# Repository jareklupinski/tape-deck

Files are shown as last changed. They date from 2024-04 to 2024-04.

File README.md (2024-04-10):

# tape-deck
a user-unfriendly design

rotating2
```
to play music, just give it a tape.
tape-deck plays to end of the tape,
reverses, and plays the other side.
```
tapedeck_1
```
HOW DOES ONE PAUSE / STOP THE TAPE?
you should finish what you started.
```
tapedeck_2
```
HOW DO I MAKE IT LOUDER OR QUIETER?
listen to louder or quieter albums.
```
tapedeck_3
```
CAN I FASTFORWARD OR REWIND AT ALL?
the artists who recorded this album
want you to listen to it like this.
```
tapedeck_4

thank you

tapedeck_5

# MAKING OF

Circuit Board Design


Schematic


Enclosure


Code
Derived from https://github.com/elehobica/pico_crp42602y_ctrl/tree/main

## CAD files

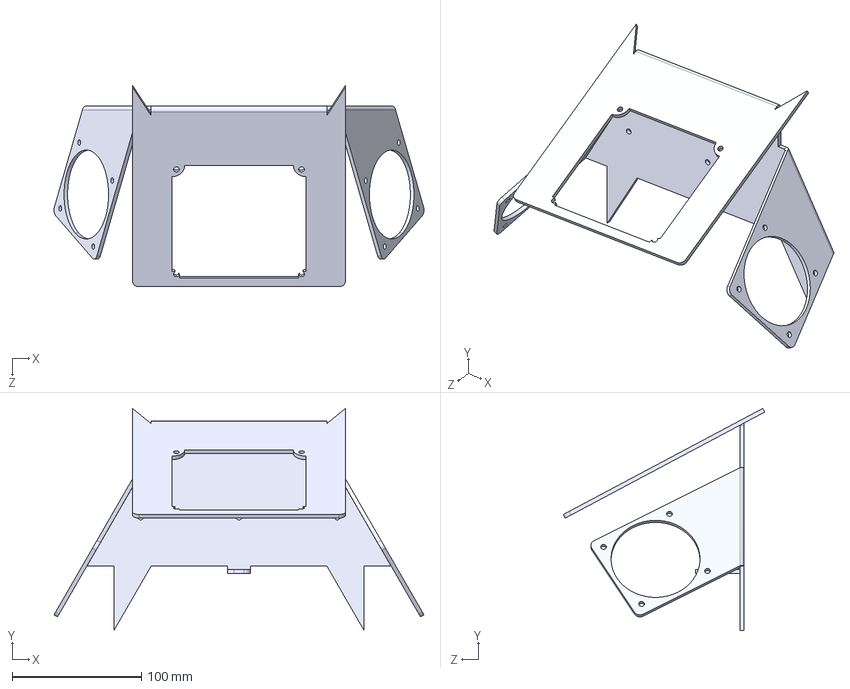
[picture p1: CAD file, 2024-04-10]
tape-deck.STEP
286.8 x 172.2 x 156.1 mm

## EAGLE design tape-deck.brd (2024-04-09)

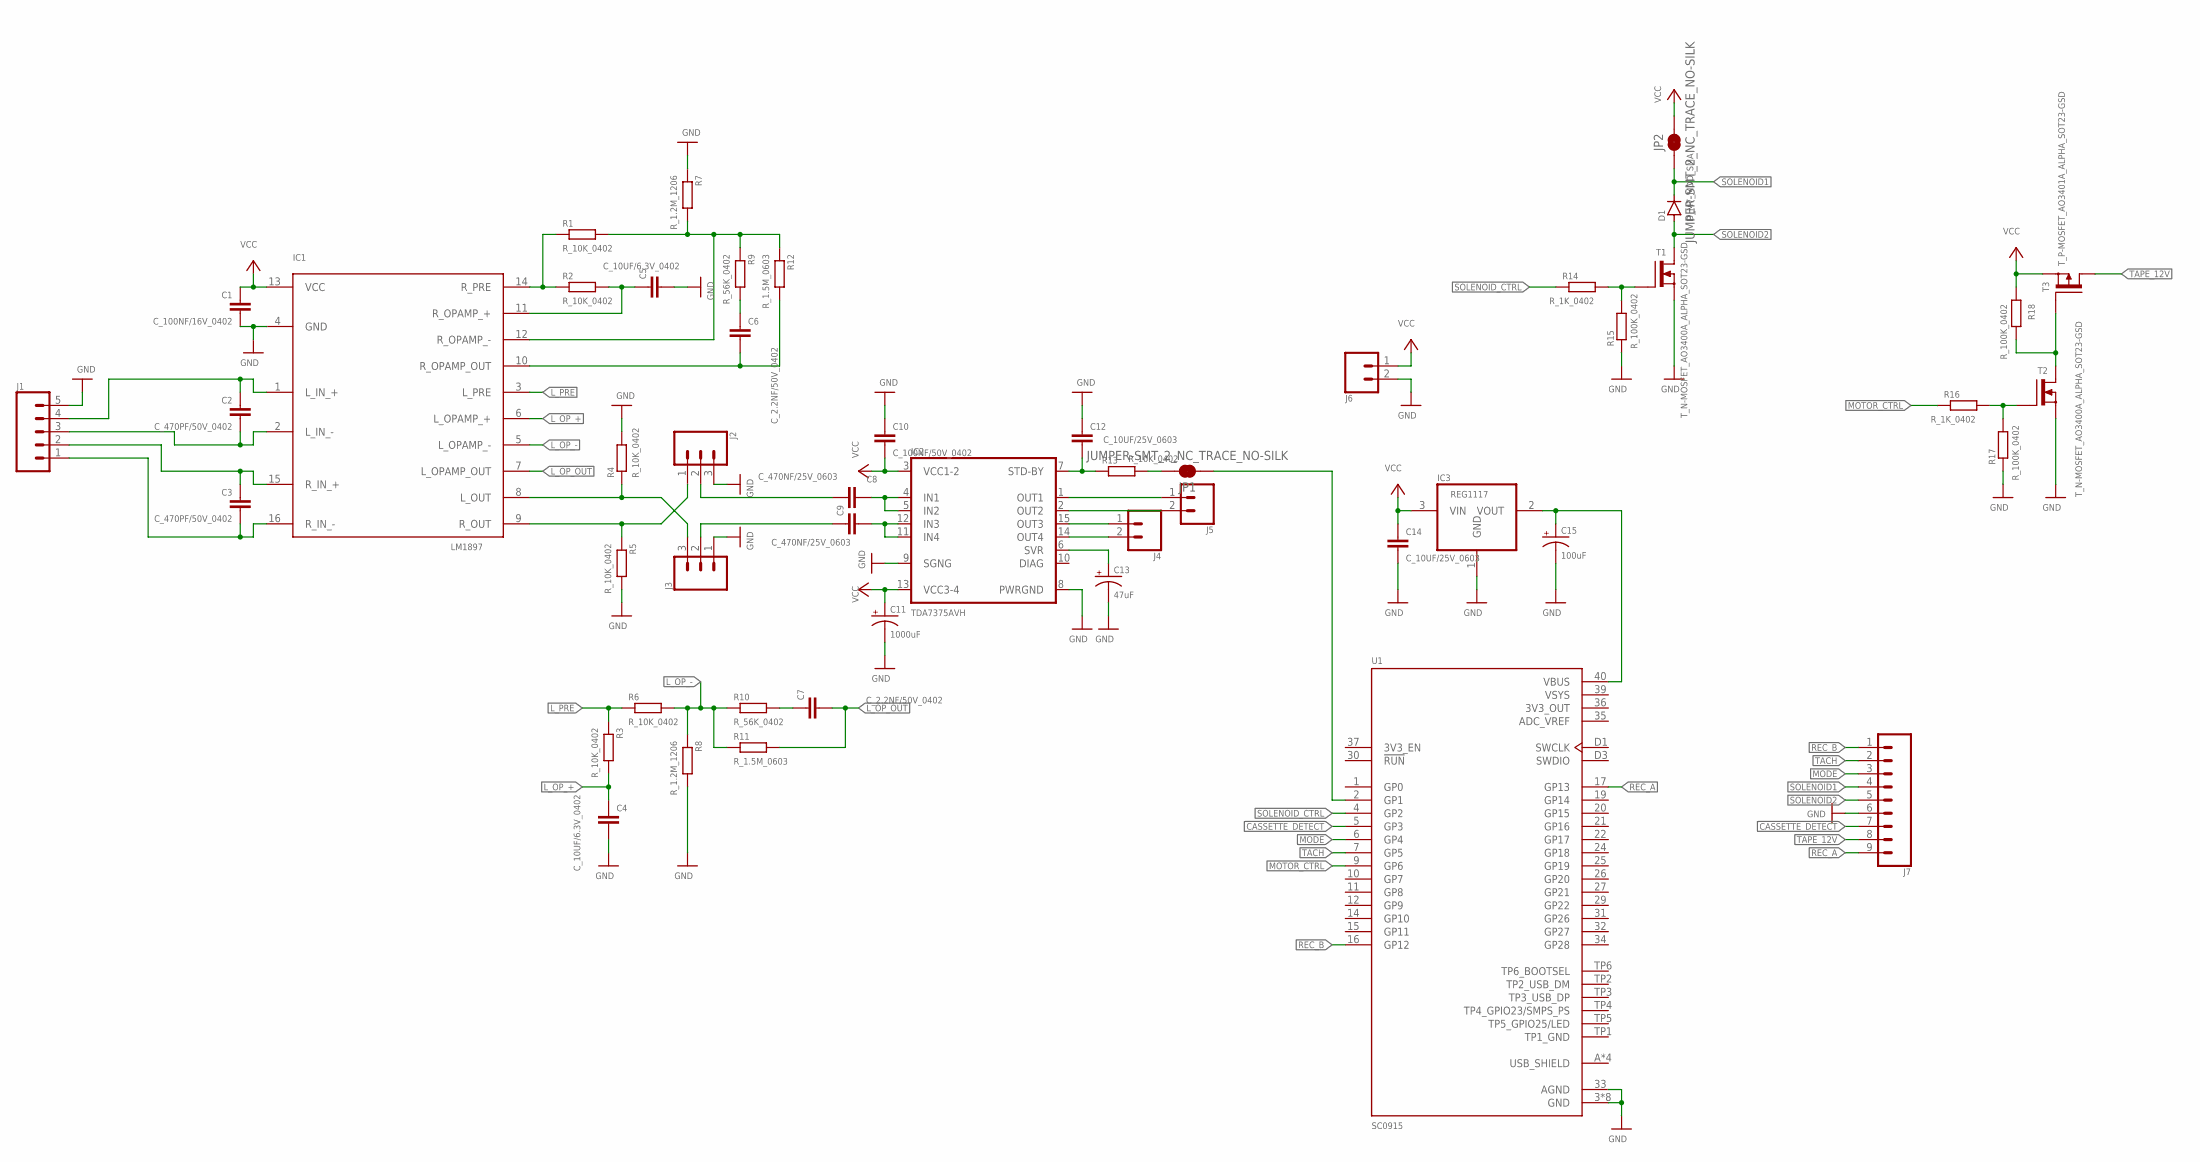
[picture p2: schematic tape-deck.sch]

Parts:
C1: C_100NF/16V_0402; C0402
C2, C3: C_470PF/50V_0402; C0402
C4, C5: C_10UF/6.3V_0402; C0402
C6, C7: C_2.2NF/50V_0402; C0402
C8, C9: C_470NF/25V_0603; C0603
C10: C_100NF/50V_0402; C0402
C11: 1000uF; 140CLH-1014
C12, C14: C_10UF/25V_0603; C0603
C13: 47uF; 140CLH-1014
C15: 100uF; 140CLH-1014
D1: D_M7_MDD_SMA; DO-214AC
IC1: LM1897; DIL16
IC2: TDA7375AVH; MULTIWATT-15H
IC3: REG1117; SOT223
J1: CONN_05PTH_LONGPADS; 1X05_LONGPADS
J2, J3: CONN_03; 1X03
J4, J5, J6: CONN_02LOCK_LONGPADS; 1X02_LOCK_LONGPADS
J7: CONN_09LONGPADS; 1X09_LONGPADS
JP1, JP2: JUMPER-SMT_2_NC_TRACE_NO-SILK; SMT-JUMPER_2_NC_TRACE_NO-SILK
R1, R2, R3, R4, R5, R6, R13: R_10K_0402; R0402
R7, R8: R_1.2M_1206; R1206
R9, R10: R_56K_0402; R0402
R11, R12: R_1.5M_0603; R0603
R14, R16: R_1K_0402; R0402
R15, R17, R18: R_100K_0402; R0402
T1, T2: T_N-MOSFET_AO3400A_ALPHA_SOT23-GSD; SOT23
T3: T_P-MOSFET_AO3401A_ALPHA_SOT23-GSD; SOT23
U1: SC0915; MODULE_SC0915

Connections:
3V3_OUT: U1.36 (3V3_OUT)
ADC_VREF: U1.35 (ADC_VREF)
CASSETTE_DETECT: J7.7, U1.5 (GP3)
GND: C1.2, C4.2, C5.2, C10.1, C11.-, C12.1, C13.-, C14.2, C15.-, IC1.4 (GND), IC2.8 (PWRGND), IC2.9 (SGNG), IC3.1 (GND), J1.5, J2.3, J3.1, J6.2, J7.6, R4.2, R5.2, R7.1, R8.2, R15.1, R17.1, T1.2 (S), T2.2 (S), U1.3 (GND), U1.8 (GND), U1.13 (GND), U1.18 (GND), U1.23 (GND), U1.28 (GND), U1.33 (AGND), U1.38 (GND), U1.D2 (GND)
L_OP_+: C4.1, IC1.6 (L_OPAMP_+), R3.2
L_OP_-: IC1.5 (L_OPAMP_-), R6.2, R8.1, R10.1, R11.1
L_OP_OUT: C7.2, IC1.7 (L_OPAMP_OUT), R11.2
L_PRE: IC1.3 (L_PRE), R3.1, R6.1
MODE: J7.3, U1.6 (GP4)
MOTOR_CTRL: R16.1, U1.9 (GP6)
unnamed: R14.2, R15.2, T1.1 (G)
unnamed: R16.2, R17.2, T2.1 (G)
unnamed: R18.1, T2.3 (D), T3.1 (G)
unnamed: C13.+, IC2.6 (SVR)
unnamed: C8.2, IC2.4 (IN1), IC2.5 (IN2)
unnamed: C9.2, IC2.11 (IN4), IC2.12 (IN3)
unnamed: JP1.2, R13.2
unnamed: C2.1, IC1.1 (L_IN_+), J1.4
unnamed: C2.2, IC1.2 (L_IN_-), J1.3
unnamed: C3.1, IC1.15 (R_IN_+), J1.2
unnamed: C15.+, IC3.2 (VOUT), U1.40 (VBUS)
unnamed: C3.2, IC1.16 (R_IN_-), J1.1
unnamed: JP1.1, U1.2 (GP1)
unnamed: C12.2, IC2.7 (STD-BY), R13.1
unnamed: IC2.1 (OUT1), J5.1
unnamed: IC2.2 (OUT2), J5.2
unnamed: IC2.15 (OUT3), J4.1
unnamed: IC2.14 (OUT4), J4.2
unnamed: IC1.14 (R_PRE), R1.1, R2.1
unnamed: C5.1, IC1.11 (R_OPAMP_+), R2.2
unnamed: IC1.12 (R_OPAMP_-), R1.2, R7.2, R9.1, R12.1
unnamed: C6.1, R9.2
unnamed: C7.1, R10.2
unnamed: C6.2, IC1.10 (R_OPAMP_OUT), R12.2
unnamed: IC1.8 (L_OUT), J3.3, R4.1
unnamed: IC1.9 (R_OUT), J2.1, R5.1
unnamed: C9.1, J3.2
unnamed: C8.1, J2.2
REC_A: J7.9, U1.17 (GP13)
REC_B: J7.1, U1.16 (GP12)
SOLENOID1: D1.C, J7.4, JP2.1
SOLENOID2: D1.A, J7.5, T1.3 (D)
SOLENOID_CTRL: R14.1, U1.4 (GP2)
TACH: J7.2, U1.7 (GP5)
TAPE_12V: J7.8, T3.3 (D)
TP1_GND: U1.TP1 (TP1_GND)
USB_SHIELD: U1.A (USB_SHIELD), U1.B (USB_SHIELD), U1.C (USB_SHIELD), U1.D (USB_SHIELD)
VCC: C1.1, C10.2, C11.+, C14.1, IC1.13 (VCC), IC2.3 (VCC1-2), IC2.13 (VCC3-4), IC3.3 (VIN), J6.1, JP2.2, R18.2, T3.2 (S)
VSYS: U1.39 (VSYS)

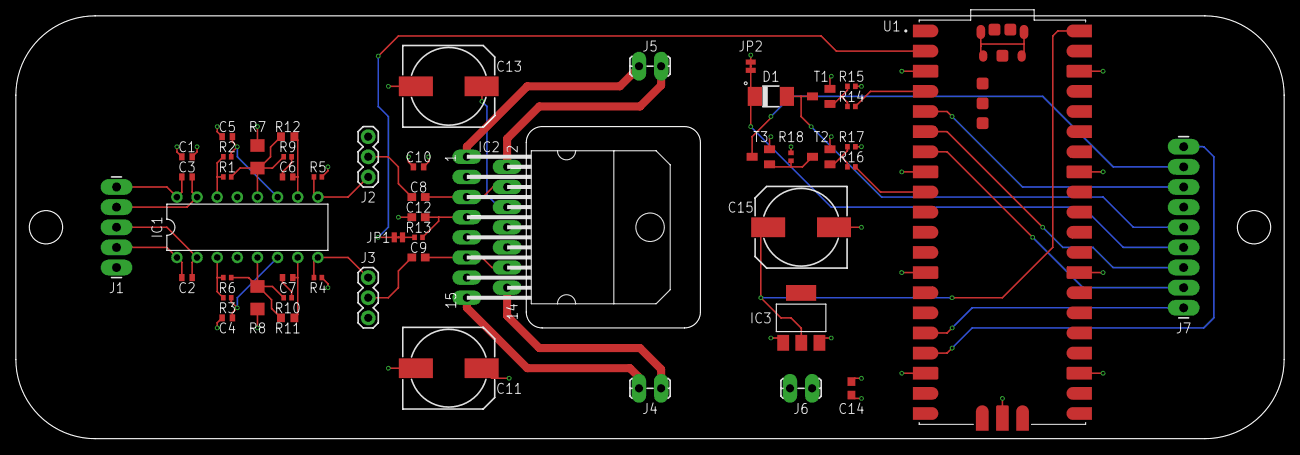
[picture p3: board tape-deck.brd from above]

Board: 4 copper layers, 160.0 x 53.3 mm, 50 parts (0 on the bottom side), 45 nets.

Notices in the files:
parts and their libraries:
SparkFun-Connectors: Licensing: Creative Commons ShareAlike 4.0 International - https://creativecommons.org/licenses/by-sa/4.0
